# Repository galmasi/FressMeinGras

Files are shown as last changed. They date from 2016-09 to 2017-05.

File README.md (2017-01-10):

# FressMeinGras
Motto: 
  Frueh frisst Gras wer ein Haeckchen werden will

Directory contents:

* Arduino/Controller: Arduino code for the rover motor controller,
  direct Bluetooth control and safety bumper code.

* Arduino/UltraSoundRadar: Arduino code for ultrasound based radar
  scanner.

* PrintedParts/UltraSoundRadar: 3D design for printed parts that make
  up the ultrasound based radar scanner.

* ImageProcessing: various opencv primitive codes to make the rover's
  cameras work with the Raspberry Pi.

* RaspberryPi/Kubelcommands: for the "Kubelwagen" implementation of
  the rover, a set of command line tools to run larger programs
  (e.g. "turn around and make a panorama snapshot).

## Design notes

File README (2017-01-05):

This project is an attempt to build an autonomous lawn mower from scratch.
Hence the project name "Fress Mein Gras" which is german for "eat my grass".

The project will go through a few steps:

a) first we will investigate whether GPS can be used to accurately 
   track the position of a rover within approximately 1 foot.
   We are considering a technology called RTKLIB for this, that relies
   on a fixed reference GPS base and the rover GPS base to eliminate
   GPS errors.
   If no possible, then other sensor technologies will be identified.
   One goal is to NOT lay down a guide line.

b) will require to build a rover base and interface with the GPS
   guided control system.
   Thoughts here are using motors typically used in wheel chairs.

c) build a charging station as the rover will likely not be able 
   to run for long times.

Hubertus Franke (frankeh)
Gheorghe Almasi (galmasi)

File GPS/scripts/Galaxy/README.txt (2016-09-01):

1) Install QPython from the app store.
2) Install sshdroid from the app store.

3) Upload the script attached as follows:

sshpass -p admin scp -P 2222 hello1.py root@<address>:/storage/emulated/0/org.qpython.qpy/scripts

4) Run the script from qpython.

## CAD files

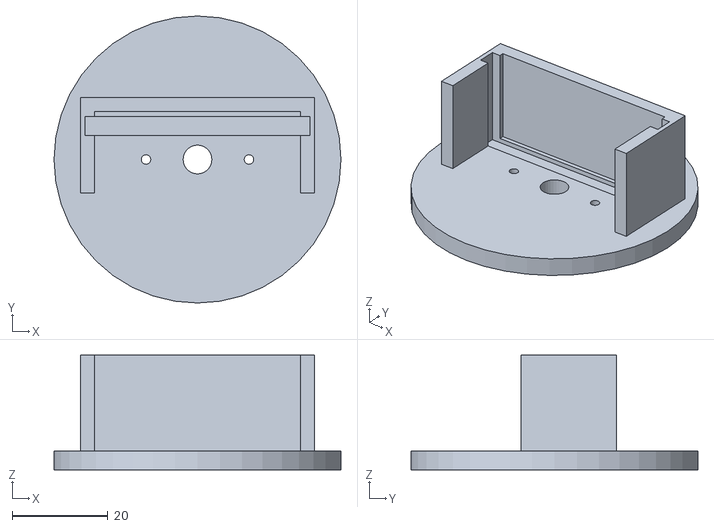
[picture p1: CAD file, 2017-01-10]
PrintedParts/UltraSoundRadar/UltraSoundRadome.stl
60.0 x 60.0 x 24.0

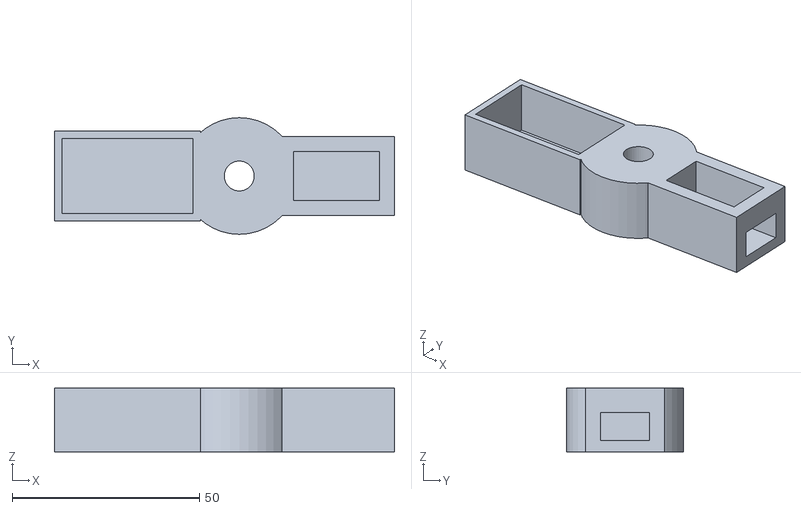
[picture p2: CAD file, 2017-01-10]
PrintedParts/UltraSoundRadar/UltraSoundBase.stl
90.9 x 31.2 x 17.0

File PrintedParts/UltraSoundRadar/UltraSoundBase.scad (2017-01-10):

module UltraSoundBase() {
  // box dimensions for servo

  w=23; 
  d=13;
  h=15;

  // box dimensions for Arduino Pro Mini

  w2=35;
  d2=20;
  
  difference() {
    union() {
      cylinder($fn=40,r=d*1.2,h=h+2);

      translate([d*2,0,h/2+1])
      cube([w+8,d+8,h+2],center=true);

      translate([-d*2.3,0,h/2+1])
      cube([w2+4,d2+4,h+2],center=true);

    }
    union() {
      translate([0,0,-1])
      cylinder($fn=40,r=4,h=h+4);

      translate([d*2,0,h/2+3])
      cube([w,d,h],center=true);

      translate([d*3,0,h/4+3])
      cube([w,d,h/2],center=true);

      translate([-d*2.3,0,h/2+3])
      cube([w2,d2,h],center=true);
    }
  }
}

UltraSoundBase();

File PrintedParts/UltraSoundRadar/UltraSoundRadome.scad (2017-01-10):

module UltraSoundRadome() {
  radarheight=20;
  radarwidth=45;

  basewidth=4;
  wallwidth=3;

  difference() {
    union() {
      cylinder($fn=40,r=30,h=basewidth);
 
      translate([0,10+wallwidth/2,radarheight/2+basewidth])
      cube([radarwidth,3,radarheight],center=true);

      translate([radarwidth/2+wallwidth/2-1,wallwidth,radarheight/2+basewidth])
      cube([3,20,radarheight],center=true);

      translate([-radarwidth/2-wallwidth/2+1,wallwidth,radarheight/2+basewidth])
      cube([3,20,radarheight],center=true);
    }
    union() {

      translate([0,7,radarheight/2+basewidth])
      cube([radarwidth+2,4,radarheight+2],center=true);

      cylinder($fn=30,r=3,h=10,center=true);

      translate([-10.75,0,0])
      cylinder($fn=20,r=1,h=10,center=true);

      translate([10.75,0,0])
      cylinder($fn=20,r=1,h=10,center=true);
  }
 }
}

UltraSoundRadome();

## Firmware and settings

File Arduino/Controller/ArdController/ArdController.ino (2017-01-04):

/* this prevents compile errors - an arduino bug */
char foo;

#include <SoftwareSerial.h>
#include <Sabertooth.h>

#include "Configuration.h"

/* *************************************************************** */
/* GLOBAL PIN ASSIGNMENTS for all functional units                 */
/* This ensures consistency - overlaps will be immediately visible */
/* *************************************************************** */

#define BTSERIAL_TX 12  
#define BTSERIAL_RX 13

#define RADAR_PINGPIN 10
#define RADAR_PONGPIN 11

#define BUMPER_PIN_0 A0
#define BUMPER_PIN_1 A1

// these overlap with the L298
#define LEDRED_PIN 6
#define LEDGRN_PIN 5
#define LEDBLU_PIN 4

#define LEGOMOTOR_PWMAPIN 3
#define LEGOMOTOR_DIRAPIN 2
#define LEGOMOTOR_PWMBPIN 9
#define LEGOMOTOR_DIRBPIN 8

#define L298N_AF (4)   // forward
#define L298N_AB (7)   // backward
#define L298N_AE (6)   // PWM
#define L298N_BF (2)   // forward
#define L298N_BB (3)   // backward
#define L298N_BE (5)   // PWM

/* other PINS used, please keep consistent 
 * L298N: 2,3,4,5,6,7
 */

/* ************************************************************ */
/* all motorvalues are byte and in the range of -127 .. +127    */
/* for indicating backward to forward or left to right (turn)   */
/* ************************************************************ */

typedef signed char motorval_t;  

/* *********************************************** */
/* 1A) Logging  (one of noop or serial)            */
/* 1B) Led status announcer                        */
/* *********************************************** */

#ifdef HAVE_SERIALPORT
#include "SerialLogger.h"
#else
#include "NoopLogger.h"
#endif

#include "LedLogger.h"

/* *********************************************** */
/*  2)  drivers for motors and sensors             */
/* ----------------------------------------------- */
/* 2A) physical motor control (lego, L298N or ST)  */
/* 2B) radar                                       */ 
/* *********************************************** */

#ifdef MOTOR_L298
  #include "MotorControl_L298N.h"
#else
  #ifdef MOTOR_SABERTOOTH
    #include "MotorControl_Sabertooth.h"
  #else
    #ifdef MOTOR_LEGO
       #include "MotorControl_Lego.h"
    #endif
  #endif
#endif

#include "Radar.h"

/* *********************************************** */
/* 3) Command Executor                             */
/* Mediates all interaction with physical devices, */
/* keeps relevant state and logs actions.          */
/* *********************************************** */

#include "CommandExecutor.h"

/* *********************************************** */
/* 4) Interpreters only talk to the executor.      */
/* Please never reach directly to the device.      */
/* ----------------------------------------------- */
/* 4A) Bluetooth + computer Interpreter            */
/* 4C) bumper pin driver                           */ 
/* *********************************************** */

#include "CommandInterpreter.h"

#ifdef HAVE_BUMPERS
  #include "Bumper.h"
#endif

void setup()
{
  Logger_init();
  LedLogger_init();

#ifdef HAVE_BUMPERS
  Bumper_init();
#endif

  MotorControl_init();
  Radar_init();
  CommandExecutor_init();
  CommandInterpreter_init();
  Logger_log("FMG ready", 0);
}

void loop()
{
  CommandInterpreter_loop();
  Radar_loop();
#ifdef HAVE_BUMPERS
  Bumper_loop();
#endif
  CommandExecutor_loop();
  LedLogger_loop();
}

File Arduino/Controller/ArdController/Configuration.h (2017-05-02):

/* *************************************************************** */
/* pre-selected configurations. pick one!                          */
/* *************************************************************** */

//#define LEGOPANZER 1
// #define TOYROBOT 1
//#define MODEL_T 1
//#define KUBELWAGEN 1
#define REDBARON 1

/* *************************************************************** */
/* These defines determine what features each configuration uses.  */
/* *************************************************************** */
/* HAVE_BUMPERS - define it if you have bumper hardware.           */
/* MOTOR_LEGO, MOTOR_SABERTOOTH, MOTOR_L298 - define one of these! */
/* HAVE_SERIALPORT - the serial port is free for logging purposes. */
/* HAVE_HEARTBEAT - set it if your bluetooth commander is sending it. */
/* *************************************************************** */

#if defined(LEGOPANZER)
  // #define HAVE_BUMPERS -- no bumpers
  #define HAVE_HEARTBEAT 1
  #define HAVE_SERIALPORT 1
  #define MOTOR_LEGO 1
  //#define HAVE_COMPUTER 1

#elif defined(TOYROBOT)
  // #define HAVE_BUMPERS  -- no bumpers
  #define HAVE_HEARTBEAT 1
  #define HAVE_SERIALPORT 1
  #define MOTOR_L298 1

#elif defined(MODEL_T)
  #define HAVE_BUMPERS 1
  #define BUMPER_NPN 1
  #define HAVE_HEARTBEAT 1
  // #define HAVE_SERIALPORT -- no serial port, since using sabertooth
  #define MOTOR_SABERTOOTH 1

#elif defined(KUBELWAGEN)
  #define HAVE_BUMPERS 1
  #define BUMPER_NPN 1
  #define HAVE_HEARTBEAT 1
  // #define HAVE_SERIALPORT -- no serial port, since using sabertooth
  #define MOTOR_SABERTOOTH 1
  #define HAVE_COMPUTER 1
  
#elif defined(REDBARON)
  // no bumpers, no computer
  #define HAVE_HEARTBEAT 1
  #define MOTOR_SABERTOOTH 1

#else
  #error "You have to choose one of (lego,toy,model_t,jeep). See top of Configuration.h"
#endif

/* *************************************************************** */
/*        conistency checks                                        */
/* *************************************************************** */

#if (defined(HAVE_SERIALPORT) && defined(MOTOR_SABERTOOTH))
  #error "Cannot have Sabertooth and serial logging operate over the same line"
#endif


/* *************************************************************** */
/* GLOBAL PIN ASSIGNMENTS for all functional units                 */
/* *************************************************************** */

#define BTSERIAL_TX 12  
#define BTSERIAL_RX 13

#define RADAR_PINGPIN 10
#define RADAR_PONGPIN 11

#define BUMPER_PIN_0 A0
#define BUMPER_PIN_1 A1

// these overlap with the L298
#define LEDRED_PIN 6
#define LEDGRN_PIN 5
#define LEDBLU_PIN 4

#define LEGOMOTOR_PWMAPIN 3
#define LEGOMOTOR_DIRAPIN 2
#define LEGOMOTOR_PWMBPIN 9
#define LEGOMOTOR_DIRBPIN 8

#define L298N_AF (4)   // forward
#define L298N_AB (7)   // backward
#define L298N_AE (6)   // PWM
#define L298N_BF (2)   // forward
#define L298N_BB (3)   // backward
#define L298N_BE (5)   // PWM

/* other PINS used, please keep consistent 
 * L298N: 2,3,4,5,6,7
 */

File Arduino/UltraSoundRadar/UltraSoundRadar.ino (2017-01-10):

/*
  This code runs a servo and an ultrasound based radar.

  Results are continuously transmitted over serial line as follows:
  <angle in degrees> <distance in cm> <crlf>

  Over the same serial line the radar can be reset with "S"
  or started with a certain scan delay: G<x>, where 
  the scan delay is 100 + 50 * x milliseconds.
*/


#include <Servo.h>

#define trigPin 13
#define echoPin 12
#define servoPin 14

int scan;
int angle;
int dangle;
int wait=200;

Servo servo1;


void setup() {
  Serial.begin (9600);
  pinMode(trigPin, OUTPUT);
  pinMode(echoPin, INPUT);

  pinMode(servoPin, OUTPUT);

  angle = 0;
  dangle=1;
  scan = 0;
  wait=200;

  servo1.attach(A0);
}



void loop() {
  long duration, distance;
  digitalWrite(trigPin, LOW);
  delayMicroseconds(20);
  digitalWrite(trigPin, HIGH);
  delayMicroseconds(10);
  digitalWrite(trigPin, LOW);
  duration = pulseIn(echoPin, HIGH);
  distance = (duration/2) / 29.1;

  if (Serial.available()) {
    char c = Serial.read();
    if (c == 'S') scan = 0;
    if (c == 'G') {
      scan = 1;
      c=Serial.read();
      wait=(c-'0')*50 + 100;
    }
  }
   
  Serial.print(angle);
  Serial.print(" ");
  if (distance >= 350 || distance <= 0){
    Serial.println("  999");
  }
  else {
    Serial.println(distance);
  }

  
  servo1.write(angle);
  if (scan) angle += dangle;
  if (angle > 178) { dangle = -5; }
  if (angle < 2) { dangle = 5; }
  
  delay(wait);
}

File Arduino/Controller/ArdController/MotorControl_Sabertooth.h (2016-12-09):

/************************************************************
 * This modules controls the Sabertooth 2x32 controller
 * The Sabertooth is to be setup in Serial Mode:
 * DIPs:  1=off, 2=off, 3..6=on (assume power supply)
 *
 * ST (Sabertooth 2x32) can be controlled in serial mode
 * in two different ways. 
 * (a) provide to the power to the individual motors directly
 * (b) control the velocity and turn
 *
 * To select (a) #define SABERTOOTH_CTRL_DUAL_MODE
 * 
 * at this point (b) is not yet working !!!!!!!!!!!!!!
 * ************************************************************/

#define SABERTOOTH_CTRL_MODE_DUAL   /* turns on dual mode (a)  */

Sabertooth ST(128);    // connect the S1 line to the TX of UNO

/* ******************* */
/* motor control state */
/* ******************* */

bool mc_stopped = true;
motorval_t mc_turn    = 0;

/* *********************************************** */
/* set pin modes, and make sure motor will be stopped */
/* *********************************************** */


inline void MotorControl_init(void) 
{
  mc_stopped = true;

  SabertoothTXPinSerial.begin(9600);

  ST.autobaud();

  // See the Sabertooth 2x60 documentation for information on ramping values.
  // There are three ranges: 1-10 (Fast), 11-20 (Slow), and 21-80 (Intermediate).
  // The ramping value 14 used here sets a ramp time of 4 seconds for full
  // forward-to-full reverse.
  //
  // 0 turns off ramping. Turning off ramping requires a power cycle.
  //
  // WARNING: The Sabertooth remembers this command between restarts AND in all modes.
  // To change your Sabertooth back to its default, call ST.setRamping(0)

  ST.setRamping(30);  // used to be 14
}

/* *********************************************** */
/* Like every motor this has a non-linear behavior */
/* with respect to voltage supplied.               */
/* We provide a curve here to get smoother scale   */
/* *********************************************** */

#define scaleM(v) (v)  // later with gear

/* *********************************************** */
/* if motor is stopped, write zeroes.              */
/* else write state values.                        */
/* *********************************************** */

//char mc_gear   = 10;

#define ST_MOTOR_LEFT  1
#define ST_MOTOR_RIGHT 2

inline void MotorControl_start(void)
{
  mc_stopped = false;
  mc_turn = 0;

  // since it was stopped all values should be
  // still set to idle
}

inline void MotorControl_stop(void)
{
  mc_stopped = true;
  mc_turn = 0;
  ST.stop();
}

inline void MotorControl_left(motorval_t speed) 
{
  if (mc_stopped) return; 
  Logger_log("Sabertoothleft", speed);
  ST.motor(ST_MOTOR_LEFT, scaleM(speed));
}

inline void MotorControl_right(motorval_t speed) 
{
  if (mc_stopped) return; 

  Logger_log("Sabertoothright", speed);
  ST.motor(ST_MOTOR_RIGHT, scaleM(speed));
}

#ifdef SABERTOOTH_CTRL_MODE_DUAL  

/*********************************************************************
 * 
 * DUAL MOTOR CONTROL MODE
 *
 *********************************************************************/

#define turnscaleL(s) ((char) ((int)(s)*(128+(mc_turn))/(int)128))
#define turnscaleR(s) ((char) ((int)(s)*(128-(mc_turn))/(int)128))

inline void MotorControl_turn(motorval_t turn)
{
  mc_turn = turn;  
}

void MotorControl_velocity(motorval_t speed)
{
  motorval_t lspeed, rspeed;
  lspeed = rspeed = speed;
  if (speed) {
    if (mc_turn < 0)
      lspeed = turnscaleL(speed);
    else {
      rspeed = turnscaleR(speed);
    }
  }
  MotorControl_left(lspeed);
  MotorControl_right(rspeed);
}

#else

/*********************************************************************
 * 
 * TURN_VELOCITY_MODE 
 *
 *********************************************************************/

inline void MotorControl_turn(motorval_t turn)
{
   if (mc_stopped) 
     turn = 0;
   ST.drive(turn);
}

void MotorControl_velocity(motorval_t speed)
{
   if (mc_stopped) 
     speed = 0;
   ST.drive(speed);
}

#endif

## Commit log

2016-08-31 + ‘.sparkleshare’ + ‘SparkleShare.txt’
2016-08-31 + ‘GPS/collected_datafiles/’
2016-08-31 + ‘GPS/collected_datafiles/083016/’
2016-08-31 + ‘GPS/collected_datafiles/083016/20160830161420_hf.txt’ + ‘GPS/collected_datafiles/083016/20160830161544_ga1.txt’ + ‘GPS/collected_datafiles/083016/20160830231412_ga2.txt’
2016-08-31 + ‘GPS/collected_datafiles/083016/usbkey.txt’
2016-08-31 / ‘GPS/collected_datafiles/hhoff/083016/data1.txt’ + ‘GPS/scripts/’
2016-08-31 + ‘GPS/scripts/.#error.py’
2016-08-31 + ‘GPS/scripts/#error.py#’
2016-08-31 - ‘GPS/scripts/#error.py#’ - ‘GPS/scripts/.#error.py’ + ‘GPS/scripts/error.py’
2016-08-31 / ‘GPS/scripts/error.py’
2016-08-31 + ‘GPS/scripts/#error.py#’ / ‘GPS/scripts/error.py’
2016-08-31 - ‘GPS/scripts/#error.py#’ / ‘GPS/scripts/error.py’
2016-08-31 - ‘GPS/scripts/.#error.py’ / ‘GPS/scripts/error.py’
2016-08-31 + ‘GPS/scripts/.#error.py’ / ‘GPS/scripts/error.py’
2016-08-31 + ‘GPS/scripts/#error.py#’ + ‘GPS/scripts/.#error.py’
2016-08-31 / ‘GPS/scripts/#error.py#’
2016-08-31 - ‘GPS/scripts/.#error.py’ < ‘GPS/scripts/#error.py#’ > ‘GPS/scripts/error.py’
2016-08-31 - ‘GPS/scripts/#error.py#’ - ‘GPS/scripts/.#error.py’ / ‘GPS/scripts/error.py’
2016-09-01 + ‘GPS/scripts/Galaxy/’
2016-09-01 + ‘GPS/scripts/Galaxy/README.txt’ + ‘GPS/scripts/Galaxy/hello1.py’
2016-09-01 update shopping with new wheels
2016-09-02 two gps trace gnuplotting
2016-10-14 + ‘Arduino/’
2016-10-14 + ‘Arduino/RotGrunLegoPanzer/’
2016-10-14 + ‘Arduino/RotGrunLegoPanzer/sketch_oct13a/sketch_oct13a.ino’
2016-10-16 / ‘Arduino/RotGrunLegoPanzer/sketch_oct13a/sketch_oct13a.ino’
2016-10-16 + ‘Arduino/RotGrunLegoPanzer/sketch_oct13a/MotorControl.h’ / ‘Arduino/RotGrunLegoPanzer/sketch_oct13a/sketch_oct13a.ino’
2016-10-16 + ‘Arduino/RotGrunLegoPanzer/sketch_oct13a/CommandInterpreter.h’ / ‘Arduino/RotGrunLegoPanzer/sketch_oct13a/MotorControl.h’ / ‘Arduino/RotGrunLegoPanzer/sketch_oct13a/sketch_oct13a.ino’
2016-10-16 / ‘Arduino/RotGrunLegoPanzer/sketch_oct13a/CommandInterpreter.h’ / ‘Arduino/RotGrunLegoPanzer/sketch_oct13a/sketch_oct13a.ino’
2016-10-16 / ‘Arduino/RotGrunLegoPanzer/sketch_oct13a/CommandInterpreter.h’ / ‘Arduino/RotGrunLegoPanzer/sketch_oct13a/MotorControl.h’ / ‘Arduino/RotGrunLegoPanzer/sketch_oct13a/sketch_oct13a.ino’
2016-10-16 / ‘Arduino/RotGrunLegoPanzer/sketch_oct13a/CommandInterpreter.h’
2016-10-16 < ‘Arduino/RotGrunLegoPanzer/sketch_oct13a/sketch_oct13a.ino’ > ‘Arduino/RotGrunLegoPanzer/sketch_oct13a/CommandExecutor.h’ / ‘Arduino/RotGrunLegoPanzer/sketch_oct13a/CommandInterpreter.h’ / ‘Arduino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
2016-10-16 / ‘Arduino/RotGrunLegoPanzer/sketch_oct13a/CommandExecutor.h’ / ‘Arduino/RotGrunLegoPanzer/sketch_oct13a/CommandInterpreter.h’ / ‘Arduino/RotGrunLegoPanzer/sketch_oct13a/MotorControl.h’
2016-10-16 / ‘Arduino/RotGrunLegoPanzer/sketch_oct13a/CommandExecutor.h’ / ‘Arduino/RotGrunLegoPanzer/sketch_oct13a/CommandInterpreter.h’ / ‘Arduino/RotGrunLegoPanzer/sketch_oct13a/MotorControl.h’ + ‘Arduino/Ro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
2016-10-16 / ‘Arduino/RotGrunLegoPanzer/sketch_oct13a/CommandInterpreter.h’ / ‘Arduino/RotGrunLegoPanzer/sketch_oct13a/MotorControl.h’ / ‘Arduino/RotGrunLegoPanzer/sketch_oct13a/Radar.h’ / ‘Arduino/RotGrunLegoP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
2016-10-16 / ‘Arduino/RotGrunLegoPanzer/sketch_oct13a/CommandExecutor.h’ / ‘Arduino/RotGrunLegoPanzer/sketch_oct13a/CommandInterpreter.h’ / ‘Arduino/RotGrunLegoPanzer/sketch_oct13a/Radar.h’ / ‘Arduino/RotGrunLe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
2016-10-16 / ‘Arduino/RotGrunLegoPanzer/sketch_oct13a/Radar.h’
2016-10-16 / ‘Arduino/RotGrunLegoPanzer/sketch_oct13a/Radar.h’ / ‘Arduino/RotGrunLegoPanzer/sketch_oct13a/sketch_oct13a.ino’
2016-10-16 / ‘Arduino/RotGrunLegoPanzer/sketch_oct13a/CommandExecutor.h’
2016-10-16 / ‘Arduino/RotGrunLegoPanzer/sketch_oct13a/CommandExecutor.h’ / ‘Arduino/RotGrunLegoPanzer/sketch_oct13a/Radar.h’
2016-10-24 expand CommandInterpreter with steering style (V,T) and negative num
2016-10-24 rename MotorControl.h
2016-10-26 Add Sabertooth MotorController
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2016-10-31 fix the mc_stopped initialization that was disabled
    [ArdController.ino, MotorControl_L298N.h, MotorControl_Sabertooth.h]
2016-12-07 1) Removed all serial output other than that of the Sabertooth. This is a temporary measure - we will need to communicate with the arduino from the raspberry, and i'd like to keep the "normal" commun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
    2) Added a lot of logging into several files, which is ironic because logging
    is disabled now. But the logging may come useful next time.
2016-12-09 Rewrote system based on discussion today.
    1) Added units for Logging (noop and Serial).
    2) Rewrote CommandExecutor to be the only one talking to physical devices.
    3) CommandExecutor has an external API that any interpreter can call.
    4) Added limiters (only partially tested at the moment).
    5) Made outline of bumper sensor unit (to be tested).
    Not tested with Sabertooth controller yet.
2016-12-09 1) At least compiled with Sabertooth 2) Added bumper logic based on LJ12A3 and a single pin.
2016-12-09 Added an initial implementation of LED driver. Uses a single 3-color LED to signal state.
2016-12-09 Recompiled for Sabertooth. Reset logging to NOOP. Left LED driver in (pins conflict with L298N!).
    Tested differential command (V and T).
    Implemented differential command for ALL motor types (in command executor).
    [ArdController.ino]
2016-12-10 1) Turned LedLogger back on, pins 4/5/6 2) Added 2 analog pins to read 2 bumpers. 3) Changed mag sensor type to NPN since the square objects HF bought are NPN. 4) Increased the "Slow" speed to 32, de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
2016-12-12 Enabled Heartbeat Disabled bumper and bumper sensors for the HF rover. Fixed vexing LED color bug.
    [ArdController.ino, CommandExecutor.h, LedLogger.h]
2016-12-15 Added a few DEFINEs at the beginning of the .ino file to determine what kind of controller we are building: serial port on/off, motor type, whether bumpers are available and so on.
2016-12-15 Added top level Configuration.h
    [Configuration.h]
2016-12-20 Initial attempt at connecting a computer into the rover's command structure.
    The computer is only able to issue secondary commands. Disconnecting from
    Bluetooth, or hitting STOP on the phone, will imobilize the rover.
    [Configuration.h]
2016-12-22 Fixes for LED loging scheme
    [ArdController.ino, Bumper.h, CommandExecutor.h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]
2016-12-23 Fixed bugs related to led logger state machine
    [Configuration.h]
2017-01-04 1) Removed software serial ports for computer control. It simply doesn't work. 2) Added hardware serial as computer control interface. 3) Removed bumpers from kubelwagen config because have dismounte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
    [Configuration.h]
2017-01-05 1) Turned bumpers back on on the controller. 2) Every LED configuration blinks now - to demonstrate that the Arduino is not stuck. 3) Added the first Raspberry command, turnandsnap, which makes the r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
    [Configuration.h]
2017-01-10 Added the first set of 3D printed parts
    [UltraSoundBase.scad, UltraSoundBase.stl, UltraSoundRadome.scad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]
2017-01-10 Added Arduino code for radar scanner.
2017-05-02 Added a configuration for the Red Baron
    [Configuration.h]
2017-09-21 Formalized old and new code for sonar pings
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2017-09-23 Added raw compass angle to sonar
